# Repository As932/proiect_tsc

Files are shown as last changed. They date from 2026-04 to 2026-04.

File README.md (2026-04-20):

# ⌚ Smartwatch Hardware Design - nRF52840

Acest repository conține documentația și fișierele de fabricație (Schematic, PCB Layout, BOM, Pick and Place, Gerbers) pentru un prototip de smartwatch ultra-low-power. Proiectul este construit în jurul ecosistemului Nordic Semiconductor și pune accent pe eficiența energetică extremă (standby de ordinul microamperilor) și pe o topologie PCB densă.

---

## 🛠️ 1. Arhitectura Hardware & Componente

Sistemul este împărțit în patru blocuri logice majore, conform schemei electrice:

### 1.1 Procesare & Conectivitate Radio
* **Microcontroller (MCU):** Nordic **nRF52840** (ARM® Cortex®-M4F la 64 MHz). Ales pentru consumul excelent în Deep Sleep și suportul nativ Bluetooth 5.0 Low Energy (BLE).
* **Cristal RTC:** 32.768 KHz (cu condensatoare de sarcină de 12pF) pentru menținerea timpului real cu un consum minim de energie.
* **Antenă:** Antenă ceramică SMD tip Chip, model **2450AT18B100E** (Johanson Technology), acompaniată de o rețea pasivă (Pi-matching network) pentru adaptarea impedanței la 2.4 GHz.

### 1.2 Interfață Utilizator (Afișaj)
* **Ecran E-Paper (e-Ink):** Conectat la PCB printr-un conector FPC cu 24 de pini (**503480-2400**).
* **Circuit de Boost E-Paper:** Panourile e-Ink necesită tensiuni specifice pentru acționarea stratului de cerneală. Placa include circuitul complet de comandă recomandat, folosind un inductor de **68uH** (L5) și diode Schottky **MBR0530** (D1, D2, D3), alături de condensatorii de filtraj asociați (10uF, 47uF).

### 1.3 Senzor de Mișcare
* **IMU (Inertial Measurement Unit):** Bosch **BMA423**. Este un accelerometru digital pe 3 axe optimizat special pentru *wearables*. Conține algoritmi hardware integrați (low-power) pentru numărarea pașilor (pedometru) și detectarea gesturilor (ex: *tilt-to-wake*), scutind MCU-ul de calcule complexe.

### 1.4 Power Management (Alimentare)
* **LiPo Charger:** **BQ25180YBGR**. Un IC dedicat managementului bateriilor mici de tip litiu-polimer. Oferă un control precis al curentului de încărcare (esențial pentru bateriile de smartwatch) și terminare sigură a ciclului de încărcare.
* **Regulator DC/DC Buck-Boost:** **RT6150AWSC**. Aceasta este o componentă critică a designului. Deoarece bateria LiPo variază de la 4.2V (plină) la 3.0V (goală), acest convertor menține tensiunea sistemului (VOUT) la un nivel stabil de 3.3V, trecând automat din modul *Buck* (coborâtor) în modul *Boost* (ridicător) pe măsură ce bateria se descarcă.

---

## 📌 2. Alocarea Pinilor nRF52840 (Interfețe)

Conexiunile fizice între MCU și periferice au fost rutate pentru a minimiza încrucișările și a asigura integritatea semnalelor.

| Componentă | Pin MCU | Interfață / Rol | Justificare & Funcționalitate |
| :--- | :---: | :---: | :--- |
| **BMA423 (IMU)** | `[P0.06]` | I2C (SDA) | Magistrală de comunicație date. |
| **BMA423 (IMU)** | `[P0.07]` | I2C (SCL) | Magistrală de clock (SCL). BMA423 lucrează ca slave I2C. |
| **BMA423 (IMU)** | `[P0.08, P1.08]` | INT | Pin de interrupt hardware. Trezește MCU-ul când detectează o mișcare a încheieturii. |
| **E-Paper (EPD)** | `[P0.03]` | SPI (MOSI) | Magistrala SPI rapidă pentru trimiterea frame-buffer-ului (imaginii) către ecran. |
| **E-Paper (EPD)** | `[P0.02]` | SPI (SCK) | Clock pentru magistrala SPI. |
| **E-Paper (EPD)** | `[P0.17]` | GPIO (BUSY) | Pin de stare (Input). MCU-ul intră în sleep și așteaptă ca acest pin să semnalizeze terminarea refresh-ului fizic al ecranului. |
| **SWD / Debug** | N/A | SWDIO / SWDCLK | Programarea se face via un conector de suprafață **TC2030-IDC** (Tag-Connect) cu 6 pad-uri, economisind masiv spațiu pe placă. |

---

## 🔋 3. Analiza Consumului de Energie (Power Budget Estimativ)

Ecosistemul hardware a fost ales pentru a maximiza autonomia unei baterii de capacitate redusă (ex: 150-200 mAh).

1.  **Standby / Deep Sleep (Regim majoritar):** * nRF52840 (RTC activ) + BMA423 (Low-power mode) + RT6150 (Quiescent) = **Aprox. 5 - 10 µA**.
    * *E-Paper-ul consumă 0 µA pentru a menține imaginea afișată.*
2.  **Evenimente Active (Scurte):**
    * **Refresh Ecran:** Curentul absorbit de circuitul de boost este de **aprox. 8 - 15 mA** timp de ~1-2 secunde, doar în momentul actualizării.
    * **Transmisie BLE:** Vârfuri scurte de curent (Tx Peak) la transmiterea pachetelor radio.
3.  **Concluzie:** Curentul mediu de descărcare este dominat de cât de des se actualizează ecranul (ex: la minut vs. la secundă) și de cât de des se sincronizează Bluetooth-ul. Într-un regim optimizat de ceas de mână, hardware-ul permite funcționarea de ordinul săptămânilor.

---

## 📐 4. Design Log & Integrare Mecanică

### Layout PCB & Integritate Electromagnetică
* **Planuri de Masă & Via Stitching:** Pentru a ecrana zgomotul (EMI) și a asigura un nivel de referință stabil pentru circuitul RF (Antenă), placa dispune de planuri de masă (`GND`) solide pe ambele straturi (TOP și BOTTOM). Acestea sunt cusute între ele (Via Stitching) pe toată suprafața disponibilă.
* **Zona RF:** S-a creat un *Polygon Cutout* (zonă liberă de cupru) strict sub și în jurul antenei ceramice 2450AT18B100E pentru a nu ecrana și a nu dezacorda propagarea undelor de 2.4 GHz.
* **Necking Down pe Alimentare:** Traseele de putere au fost rutate pe cât posibil cu o lățime de 0.3mm. Totuși, în zonele foarte congestionate (în proximitatea PMIC-ului BQ25180 și a procesorului), traseele au fost îngustate local (*neck-down*) pentru a permite amplasarea condensatorilor de decuplare (ex: C38, C39) cât mai aproape de pini.

### Status Integrare 3D & Carcasă (Mechanical)
1. **Modelul Nativ:** Fișierul `.f3z` din folderul *Mechanical* conține designul nativ din Fusion 360 al plăcii. Au fost rezolvate erorile vizuale de extrudare a pachetelor lipsă (cărămizile negre) specifice componentelelor custom.
2. **Exploded View (WIP):** Etapa de asamblare este în desfășurare. S-a realizat exportul plăcii (Switch to 3D PCB). Amplasarea conceptuală a dispozitivului urmează un design tip "sandwich":
   * **Bateria:** Plasată sub PCB (pe fața BOTTOM).
   * **Ecranul E-Paper:** Poziționat deasupra PCB-ului (pe fața TOP), conectat prin cablul FPC îndoit.
   * *Notă:* Modelele 3D exacte pentru baterie și display urmează să fie importate și aliniate pentru exportul final de ansamblu tip `.step`.

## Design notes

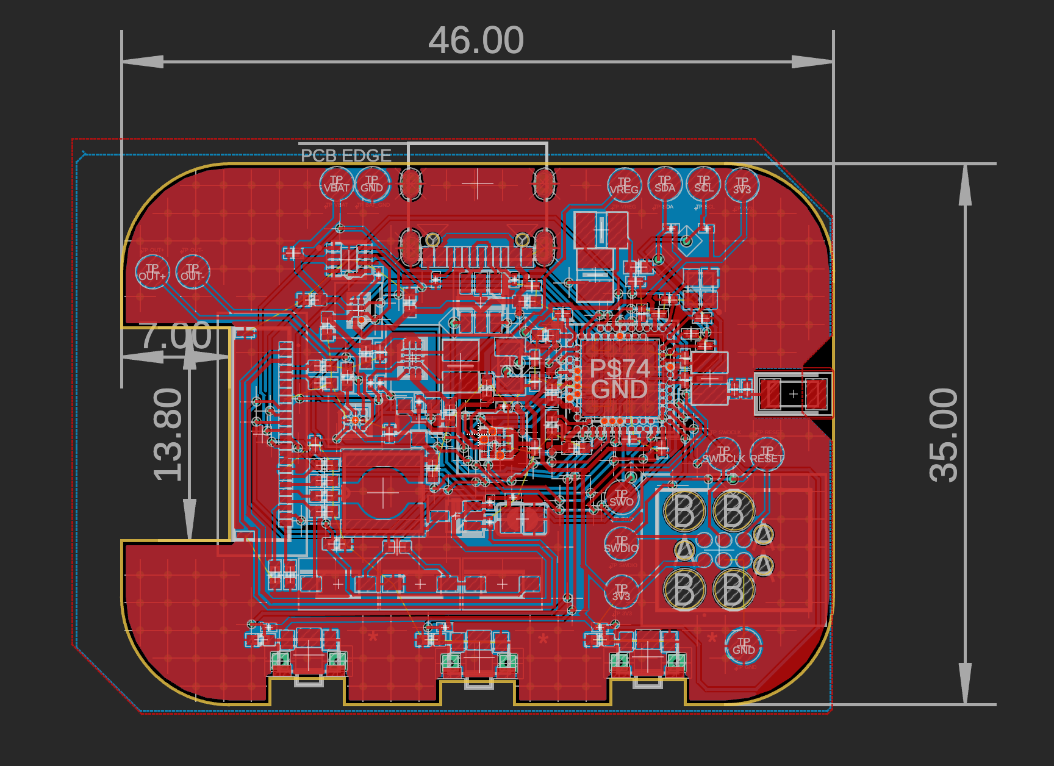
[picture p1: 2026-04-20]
Images/Screenshot 2026-04-20 at 15.04.27.png

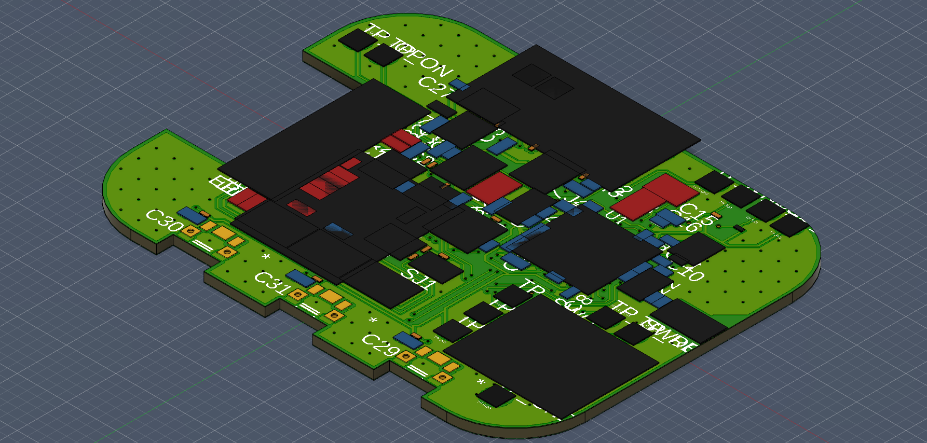
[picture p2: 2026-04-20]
Images/Screenshot 2026-04-20 at 15.04.39.png

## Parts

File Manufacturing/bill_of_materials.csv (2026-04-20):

Reference Designators | Quantity | Description | Package | Value | Manufacturer | Manufacturer Part Number | Vendor | Vendor Part Number | Top/Bottom
 | 1 | Board | Board
ANT1 | 1 | Antennas 2.45GHz ANTENNA | 2450AT18B100E_ANTC3216X140N | 2450AT18B100E |  |  |  |  | Top
C1-EP-DR, C24, C39 | 3 | Generic chip capacitor | NORDIC_NRF_3_RESC0402_N | 10uF |  |  |  |  | Top
C1, C2, C17, C18 | 4 | Generic chip capacitor | NORDIC_NRF_3_RESC0201_N | 12pF |  |  |  |  | Top
C2-EP-DR, C6, C14, C20, C21, C43 | 6 | Generic chip capacitor | NORDIC_NRF_3_RESC0402_N | 4.7uF |  |  |  |  | Top
C3, C4 | 2 | Generic chip capacitor | NORDIC_NRF_3_RESC0201_N | 1pF |  |  |  |  | Top
C5, C7, C8, C12, C19 | 5 | Generic chip capacitor | NORDIC_NRF_3_RESC0201_N | 100nF |  |  |  |  | Top
C9 | 1 | Generic chip capacitor | NORDIC_NRF_3_RESC0201_N | 820pF N.C. |  |  |  |  | Top
C10, C13, C22 | 3 | Generic chip capacitor | NORDIC_NRF_3_RESC0201_N | N.C. |  |  |  |  | Top
C11 | 1 | Generic chip capacitor | NORDIC_NRF_3_RESC0201_N | 100pF |  |  |  |  | Top
C15 | 1 | Generic chip capacitor | NORDIC_NRF_3_RESC0402_N | 1.0uF |  |  |  |  | Top
C16 | 1 | Generic chip capacitor | NORDIC_NRF_3_RESC0201_N | 47nF |  |  |  |  | Top
C23, C27, C34, C42, EPD_C5 | 5 | Generic chip capacitor | NORDIC_NRF_3_RESC0201_N | 0.1uF |  |  |  |  | Top
C25, C33 | 2 | Generic chip capacitor | NORDIC_NRF_3_RESC0402_N | 22uF |  |  |  |  | Top
C29, C30, C31, C32, C37, C38, EPD_C1, EPD_C2, EPD_C6, EPD_C7, EPD_C8, EPD_C9, EPD_C10, EPD_C11, EPD_C12 | 15 | Generic chip capacitor | NORDIC_NRF_3_RESC0402_N | 1uF |  |  |  |  | Top
D2, D4, D5 | 3 | ON SEMICONDUCTOR - MBR0530 - DIODE, SCHOTTKY, 0.5A, 30V, SOD-123 | SOD3716X135N | MBR0530 |  |  |  |  | Top
D3 | 1 | Low Cap. ESD Protection Auto SOT-23-6 STMicroelectronics USBLC6-2SC6Y, Dual Uni-Directional TVS Diode Array, 6-Pin SOT-23 | SOT95P280X145-6N | USBLC6-2SC6Y |  |  |  |  | Top
IC1 | 1 | Charger IC Lithium Ion/Polymer, Lithium Iron Phosphate 8-DSBGA (1.6x1.1) | BQ25180YBGR_BGA8C40P2X4_100X155X50 | BQ25180YBGR |  |  |  |  | Top
IC2 | 1 | Haptic Driver for ERM/LRA with Built-In Library and Smart Loop Architecture | DRV2605YZFR_BGA9C50P3X3_144X144X62 | DRV2605YZFR |  |  |  |  | Top
IC3 | 1 | Accelerometers Triaxial low-g 12bit Acceleration Sensor | BMA423_BMA423 | BMA423 |  |  |  |  | Top
IC9 | 1 | Buck-Boost Regulator Positive Output Step-Up/Step-Down I2C DC-DC Controller IC 15-WL-CSP (BSC) (1.4x2.3) | RT6160AWSC_BGA15C40P3X5_140X230X60 | RT6160AWSC |  |  |  |  | Top
J1 | 1 | FFC & FPC Connectors 0.5mm FPC RA SMT Dual Contact 24Ckt | 503480-2400_5034802400 | 503480-2400 |  |  |  |  | Top
J2 | 1 | CABLE ADAPTER 6 POS | TC2030-IDC_TC2030IDC | TC2030-IDC |  |  |  |  | Top
J4 | 1 | Check availability | KINGHELM_KH-TYPE-C-16P | KH-TYPE-C-16P |  |  |  |  | Top
L1 | 1 | SMD / SMT Inductors (Coils), L=0.47?H, L x W x T : | MLP2016SR47MT0S1_INDC2016X100N | 3.9nH |  |  |  |  | Top
L2 | 1 | SMD / SMT Inductors (Coils), L=0.47?H, L x W x T : | MLP2016SR47MT0S1_INDC2016X100N | 10uH |  |  |  |  | Top
L3 | 1 | SMD / SMT Inductors (Coils), L=0.47?H, L x W x T : | MLP2016SR47MT0S1_INDC2016X100N | 15nH |  |  |  |  | Top
L5 | 1 |  | ESP32_C6_LIBRARY_2_IND_4828-WE-TPC_WRE | 68uH |  |  |  |  | Top
L7 | 1 | SMD / SMT Inductors (Coils), L=0.47?H, L x W x T : | MLP2016SR47MT0S1_INDC2016X100N | FTC252012SR47MBCA |  |  |  |  | Top
Q1 | 1 | P-channel MOSFETs | ESP32_WROVER_SPARKFUN-DISCRETESEMI_SOT23-3 | 20V/4.2A/52mΩ/1.4W |  |  |  |  | Top
Q3 | 1 | MOSFET N-Ch 30V 1.5A TrenchFET SC70 Vishay Si1308EDL-T1-GE3 N-channel MOSFET Transistor, 1.5 A, 30 V, 3-Pin SC-70 | SOT65P210X110-3N | SI1308EDL-T1-GE3 |  |  |  |  | Top
R_PWR_EPD, R2_EP_DR, R5, R7, R8, R9 | 6 | 7.68k 0201 Thin Film Surface Mount Fixed Resistor +/-0.5% 0.031W CPF0201D7K68C1 | CPF0201D7K68C1_0201 | 10K |  |  |  |  | Top
R_TYPE_SEL | 1 | 7.68k 0201 Thin Film Surface Mount Fixed Resistor +/-0.5% 0.031W CPF0201D7K68C1 | CPF0201D7K68C1_0201 | 2.2 |  |  |  |  | Top
R1_EP_DR | 1 | 7.68k 0201 Thin Film Surface Mount Fixed Resistor +/-0.5% 0.031W CPF0201D7K68C1 | CPF0201D7K68C1_0201 | 0.47 |  |  |  |  | Top
R1_USB, R2_USB | 2 | 7.68k 0201 Thin Film Surface Mount Fixed Resistor +/-0.5% 0.031W CPF0201D7K68C1 | CPF0201D7K68C1_0201 | 5K1 |  |  |  |  | Top
R2, R3, R4 | 3 | 7.68k 0201 Thin Film Surface Mount Fixed Resistor +/-0.5% 0.031W CPF0201D7K68C1 | CPF0201D7K68C1_0201 | 0 |  |  |  |  | Top
R17, R18 | 2 | 7.68k 0201 Thin Film Surface Mount Fixed Resistor +/-0.5% 0.031W CPF0201D7K68C1 | CPF0201D7K68C1_0201 | 3K3 |  |  |  |  | Top
SJ1 | 1 | SMD solder JUMPER | JUMPER_SJ |  |  |  |  |  | Top
SW2, SW3, SW4 | 3 |  | SW_EVP-AKE31A_PAN | 0 |  |  |  |  | Top
TP_3.3V, TP_3V3, TP_BAT_GND, TP_GND, TP_ON, TP_OP, TP_RESET, TP_SCL, TP_SDA, TP_SWDCLK, TP_SWDIO, TP_SWO, TP_VBAT, TP_VREG | 14 | Test pad | HECTOR_WATCH_1_TP20R | HECTOR_WATCH_1_TPTP20R |  |  |  |  | Top
U1 | 1 | nRF52840 | NORDIC_NRF_4_AQFN50P700X700X85_HS-74N | NRF52840_QF |  |  |  |  | Top
U3 | 1 | Check availability | SON50P200X200X80-9N | MAX17048G+T10 |  |  |  |  | Top
X1 | 1 |  | NORDIC_NRF_BT-XTAL_2016_N | 32MHz |  |  |  |  | Top
X2 | 1 |  | NORDIC_NRF_1_XTAL_3215_N | 32.768kHz |  |  |  |  | Top

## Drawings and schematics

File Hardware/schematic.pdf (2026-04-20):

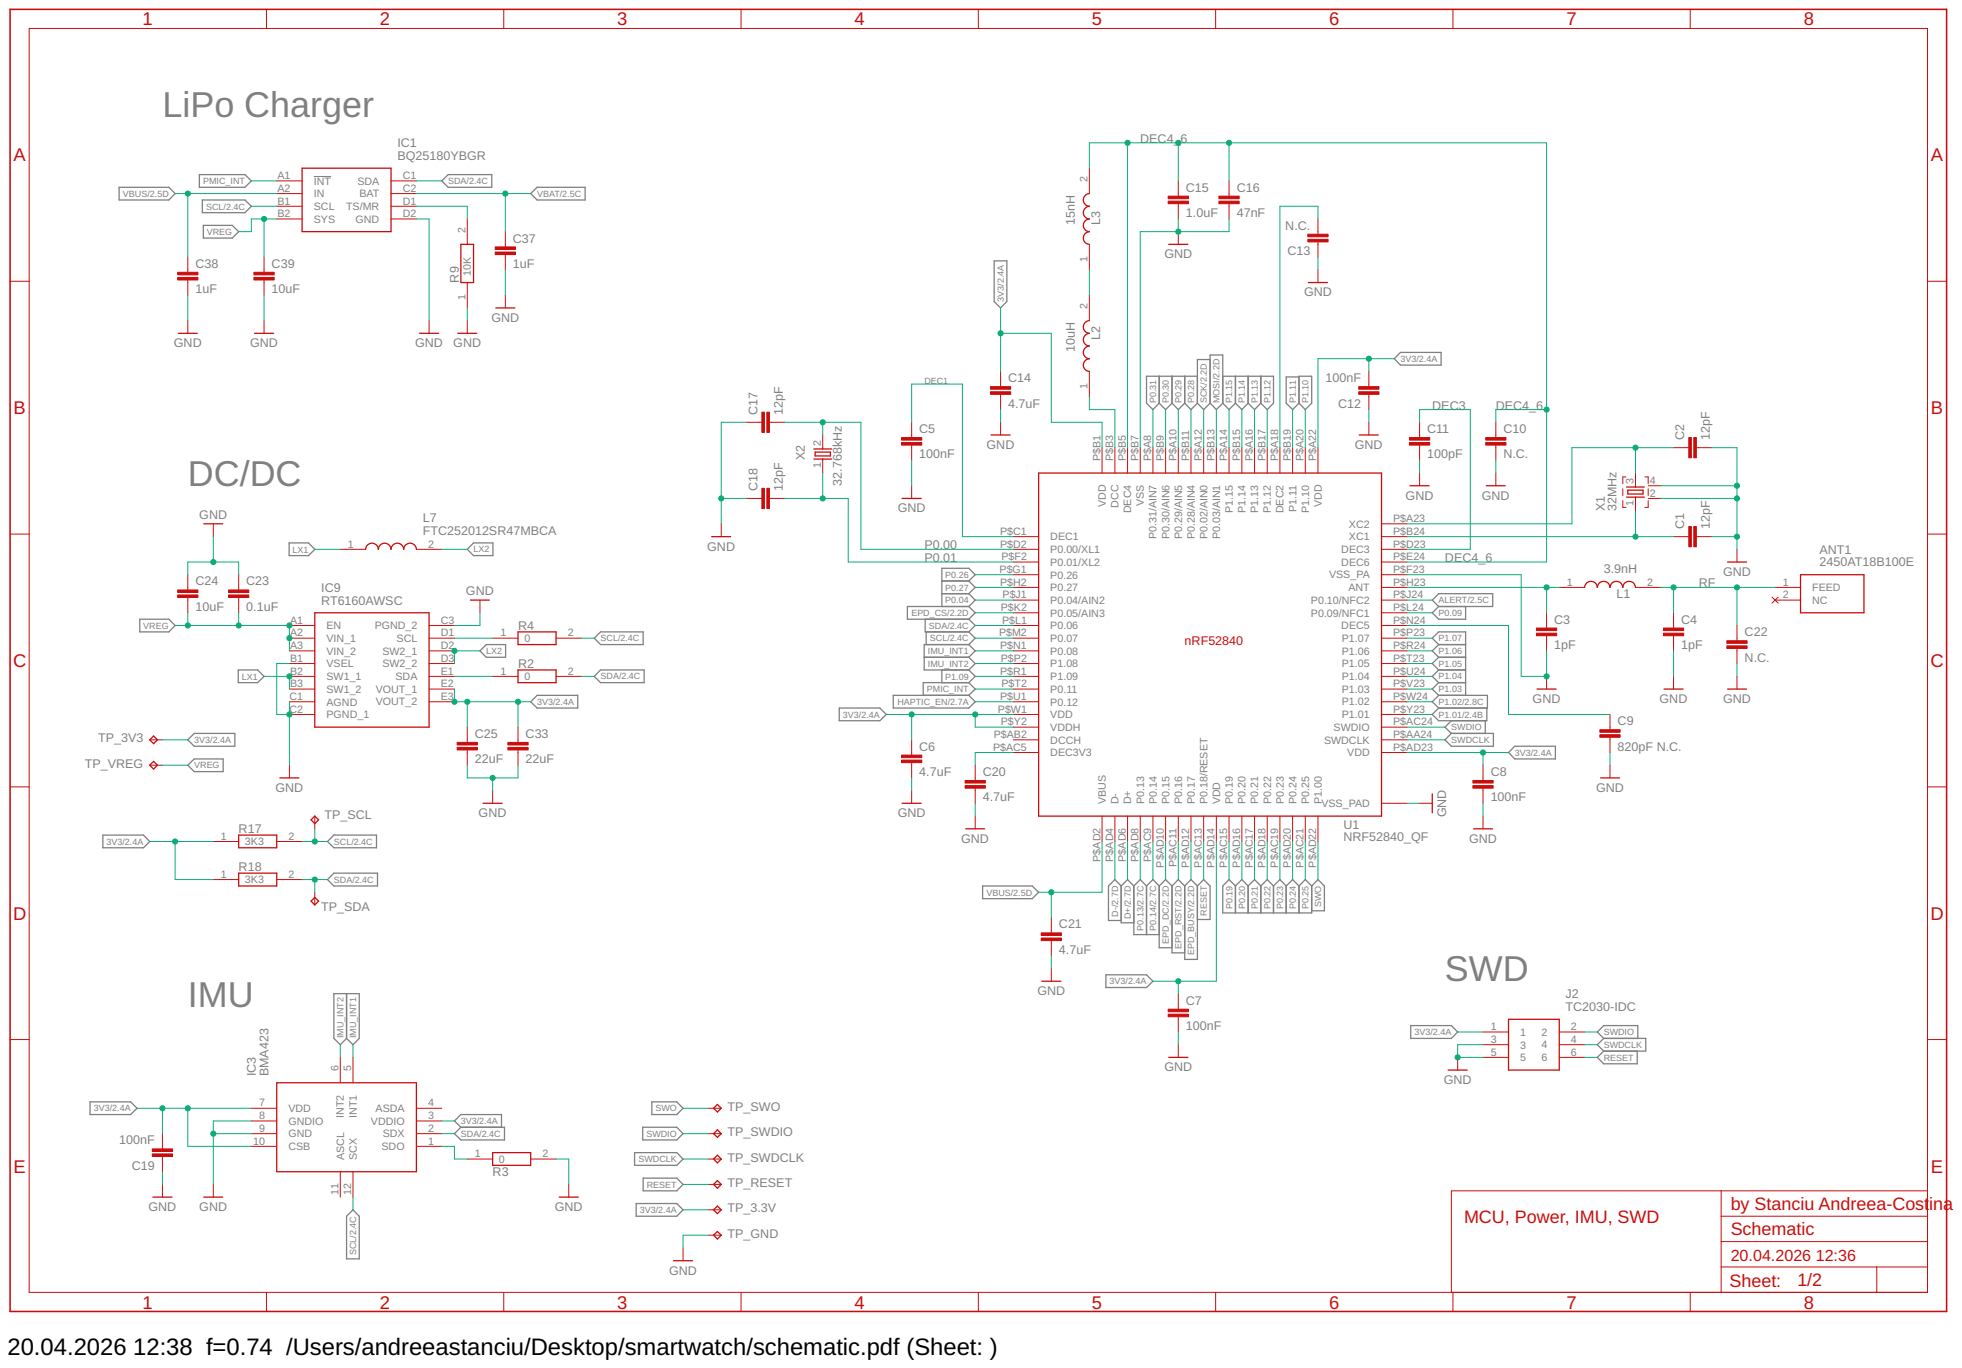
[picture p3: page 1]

MHz GND GND GND

by Stanciu Andreea-Costina Sheet:
Schematic

MCU, Power, IMU, SWD

20.04.2026 12:38 f=0.74 /Users/andreeastanciu/Desktop/smartwatch/schematic.pdf (Sheet: )

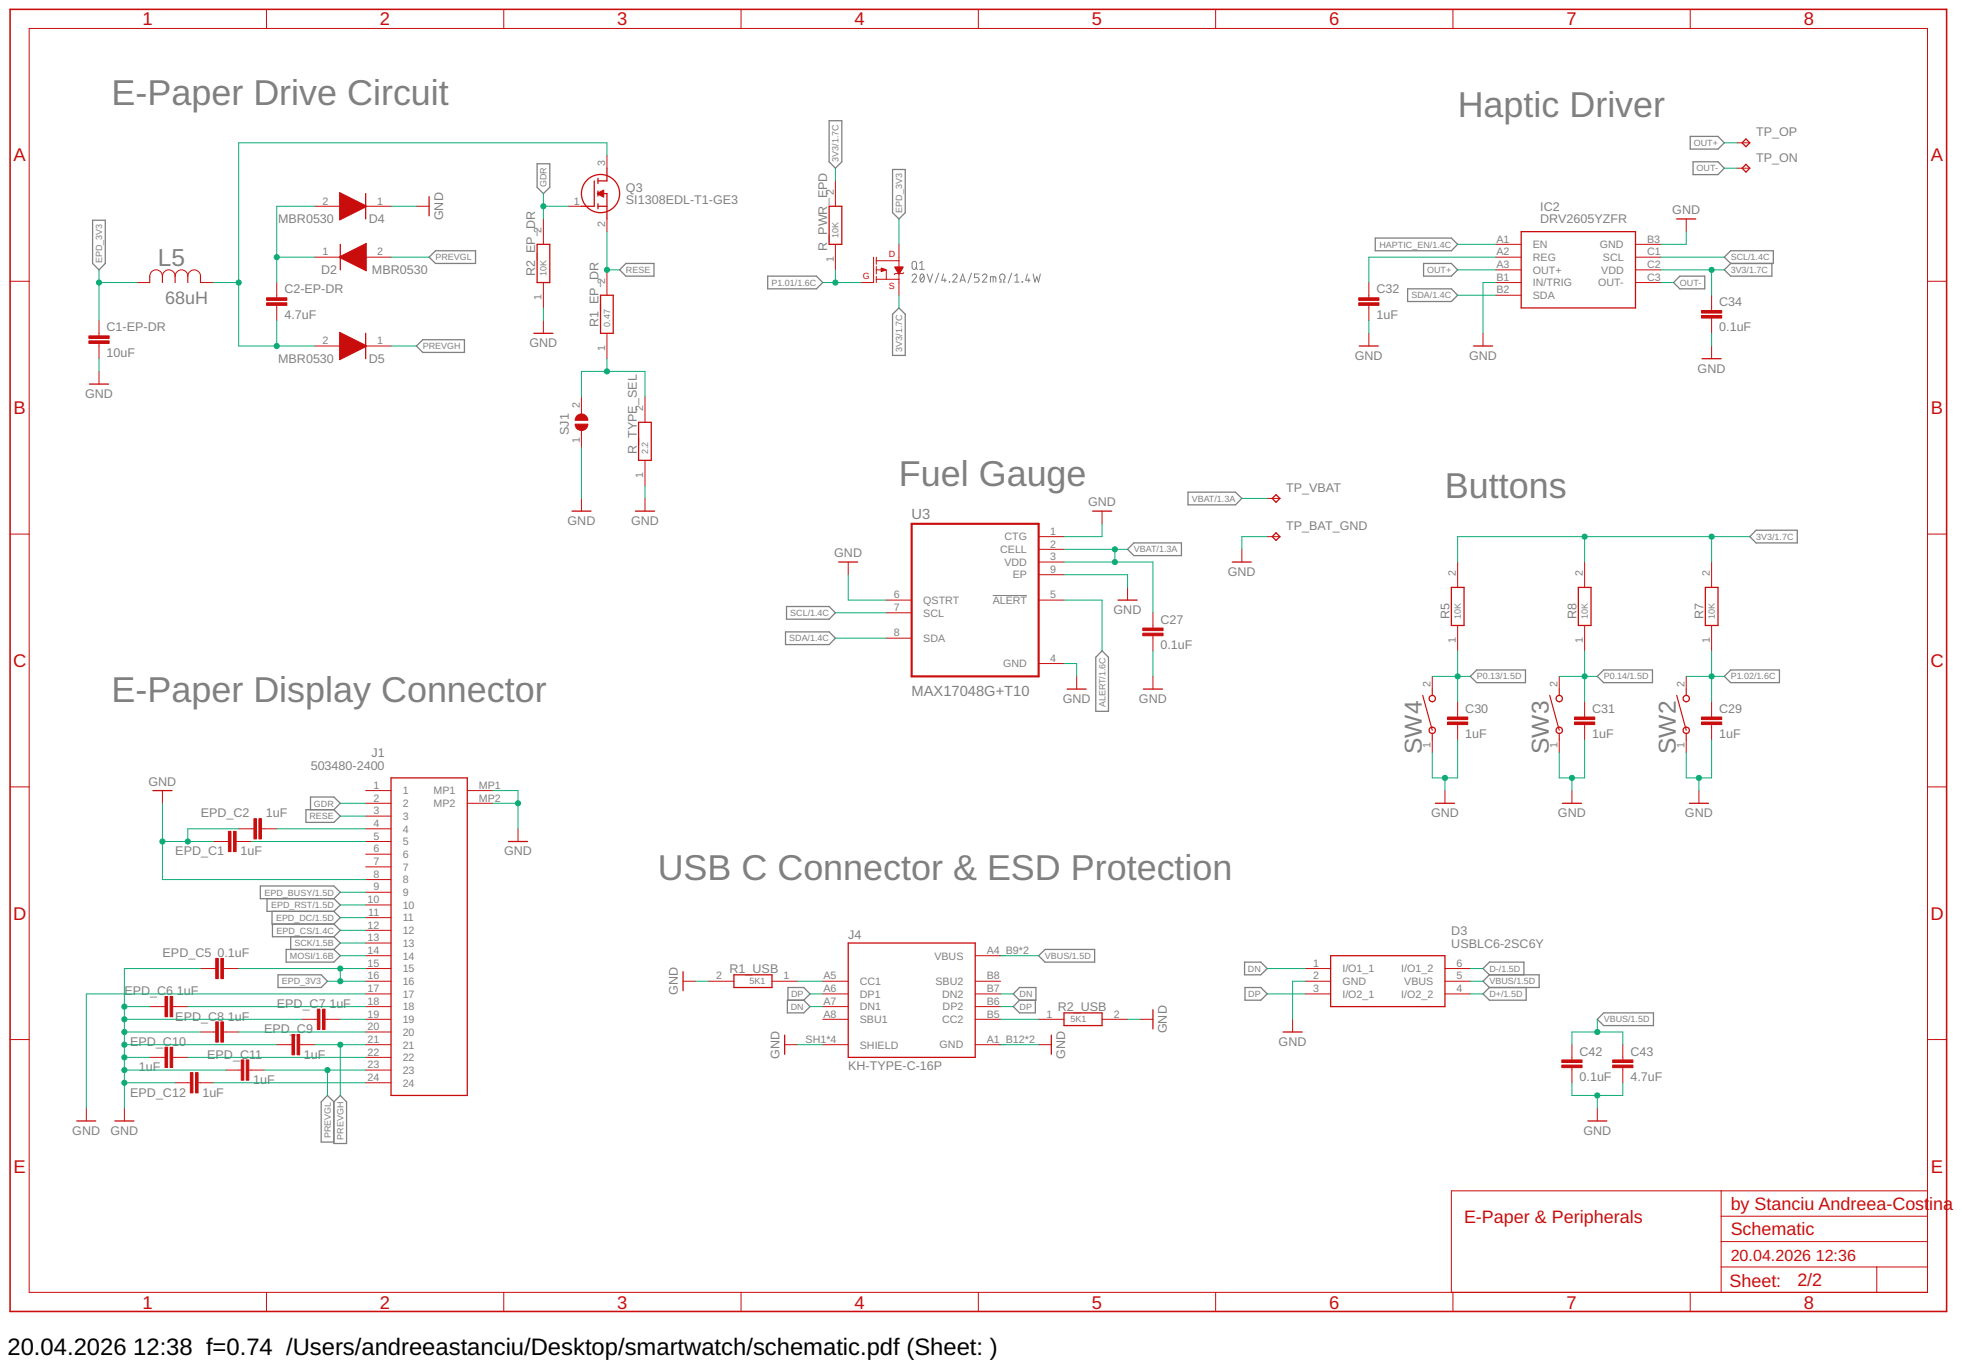
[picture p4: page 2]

USB C Connector & ESD Protection

20.04.2026 12:38 f=0.74 /Users/andreeastanciu/Desktop/smartwatch/schematic.pdf (Sheet: )

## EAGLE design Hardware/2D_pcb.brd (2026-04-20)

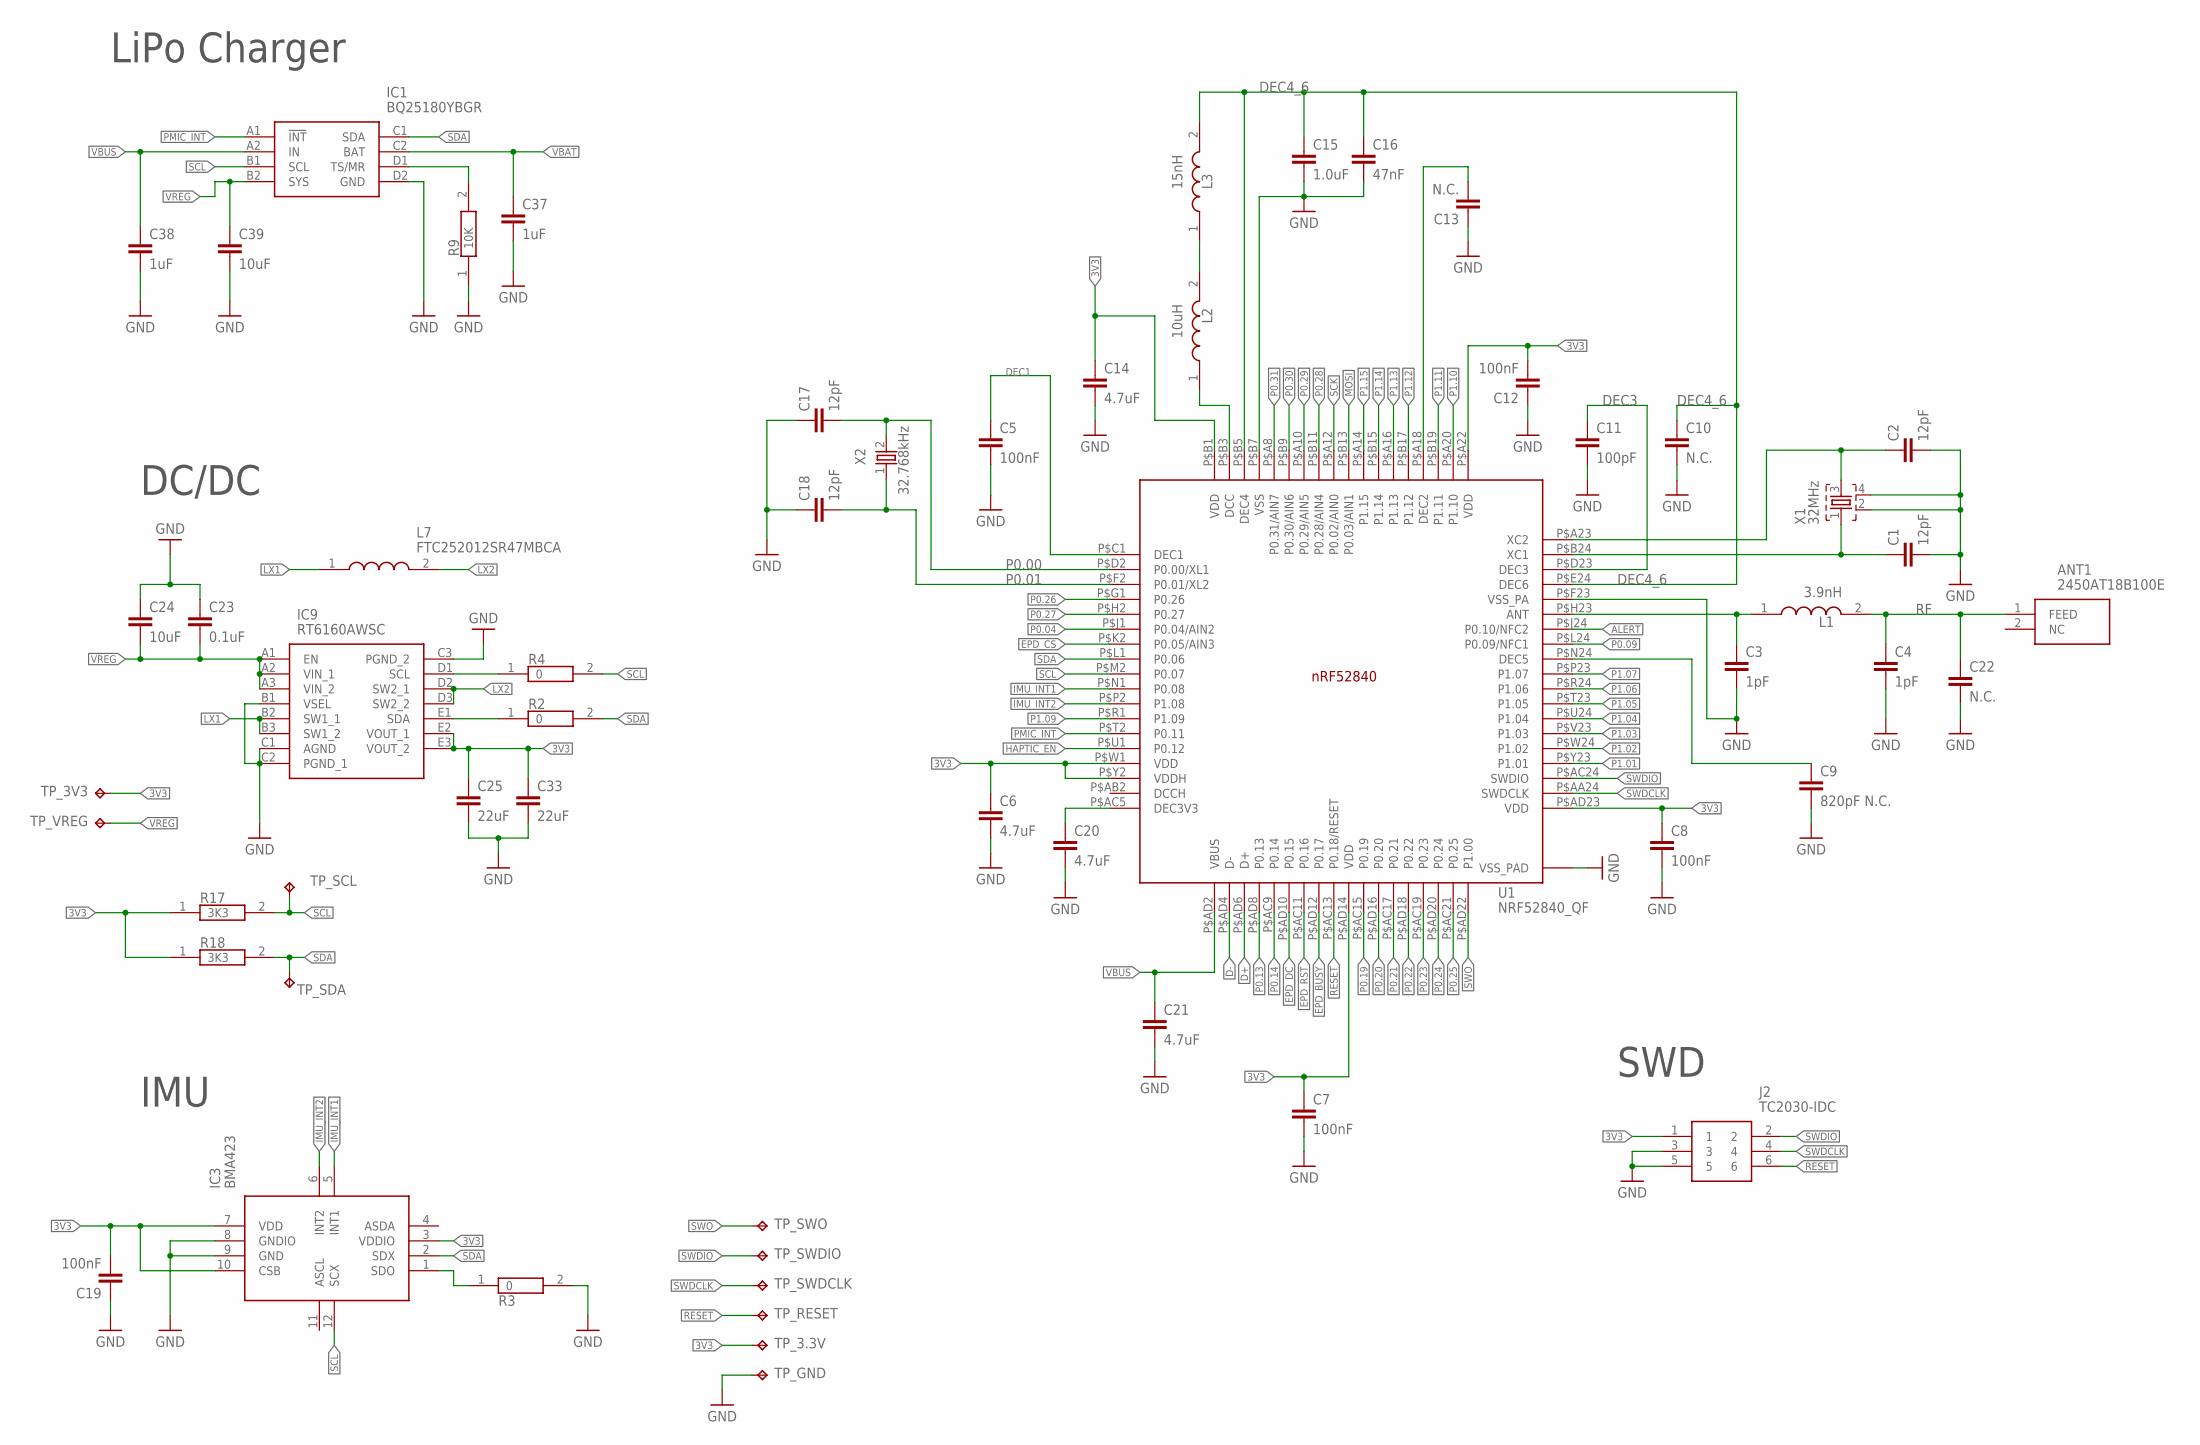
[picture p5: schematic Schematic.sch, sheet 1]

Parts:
ANT1: 2450AT18B100E; 2450AT18B100E_ANTC3216X140N
C1, C2, C17, C18: 12pF; NORDIC_NRF_3_RESC0201_N
C3, C4: 1pF; NORDIC_NRF_3_RESC0201_N
C5, C7, C8, C12, C19: 100nF; NORDIC_NRF_3_RESC0201_N
C6, C14, C20, C21: 4.7uF; NORDIC_NRF_3_RESC0402_N
C9: 820pF N.C.; NORDIC_NRF_3_RESC0201_N
C10, C13, C22: N.C.; NORDIC_NRF_3_RESC0201_N
C11: 100pF; NORDIC_NRF_3_RESC0201_N
C15: 1.0uF; NORDIC_NRF_3_RESC0402_N
C16: 47nF; NORDIC_NRF_3_RESC0201_N
C23: 0.1uF; NORDIC_NRF_3_RESC0201_N
C24, C39: 10uF; NORDIC_NRF_3_RESC0402_N
C25, C33: 22uF; NORDIC_NRF_3_RESC0402_N
C37, C38: 1uF; NORDIC_NRF_3_RESC0402_N
IC1: BQ25180YBGR; BQ25180YBGR_BGA8C40P2X4_100X155X50
IC3: BMA423; BMA423_BMA423
IC9: RT6160AWSC; RT6160AWSC_BGA15C40P3X5_140X230X60
J2: TC2030-IDC; TC2030-IDC_TC2030IDC
L1: 3.9nH; MLP2016SR47MT0S1_INDC2016X100N
L2: 10uH; MLP2016SR47MT0S1_INDC2016X100N
L3: 15nH; MLP2016SR47MT0S1_INDC2016X100N
L7: FTC252012SR47MBCA; MLP2016SR47MT0S1_INDC2016X100N
R2, R3, R4: 0; CPF0201D7K68C1_0201
R9: 10K; CPF0201D7K68C1_0201
R17, R18: 3K3; CPF0201D7K68C1_0201
TP_3.3V, TP_3V3: HECTOR_WATCH_1_TPTP20R; HECTOR_WATCH_1_TP20R
TP_GND: HECTOR_WATCH_1_TPTP20R; HECTOR_WATCH_1_TP20R
TP_RESET: HECTOR_WATCH_1_TPTP20R; HECTOR_WATCH_1_TP20R
TP_SCL: HECTOR_WATCH_1_TPTP20R; HECTOR_WATCH_1_TP20R
TP_SDA: HECTOR_WATCH_1_TPTP20R; HECTOR_WATCH_1_TP20R
TP_SWDCLK: HECTOR_WATCH_1_TPTP20R; HECTOR_WATCH_1_TP20R
TP_SWDIO: HECTOR_WATCH_1_TPTP20R; HECTOR_WATCH_1_TP20R
TP_SWO: HECTOR_WATCH_1_TPTP20R; HECTOR_WATCH_1_TP20R
TP_VREG: HECTOR_WATCH_1_TPTP20R; HECTOR_WATCH_1_TP20R
U1: NRF52840_QF; NORDIC_NRF_4_AQFN50P700X700X85_HS-74N
X1: 32MHz; NORDIC_NRF_BT-XTAL_2016_N
X2: 32.768kHz; NORDIC_NRF_1_XTAL_3215_N

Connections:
3V3: C6.1, C7.1, C8.1, C12.2, C14.1, C19.2, C25.1, C33.1, IC3.3 (VDDIO), IC3.7 (VDD), IC3.10 (CSB), IC9.E2 (VOUT_1), IC9.E3 (VOUT_2), J2.1, R17.1, R18.1, TP_3.3V.TP, TP_3V3.TP, U1.P$A22 (VDD), U1.P$AD14 (VDD), U1.P$AD23 (VDD), U1.P$B1 (VDD), U1.P$W1 (VDD), U1.P$Y2 (VDDH); also elsewhere on the board
ALERT: U1.P$J24 (P0.10/NFC2); also elsewhere on the board
D+: U1.P$AD6 (D+); also elsewhere on the board
D-: U1.P$AD4 (D-); also elsewhere on the board
DEC1: C5.1, U1.P$C1 (DEC1)
DEC3: C11.1, U1.P$D23 (DEC3)
DEC4_6: C10.1, C15.1, C16.1, L3.2, U1.P$B5 (DEC4), U1.P$E24 (DEC6)
EPD_BUSY: U1.P$AD12 (P0.17); also elsewhere on the board
EPD_CS: U1.P$K2 (P0.05/AIN3); also elsewhere on the board
EPD_DC: U1.P$AD10 (P0.15); also elsewhere on the board
EPD_RST: U1.P$AC11 (P0.16); also elsewhere on the board
GND: C1.2, C2.2, C3.2, C4.2, C5.2, C6.2, C7.2, C8.2, C9.2, C10.2, C11.2, C12.1, C13.1, C14.2, C15.2, C16.2, C17.1, C18.1, C19.1, C20.2, C21.2, C22.2, C23.1, C24.1, C25.2, C33.2, C37.2, C38.2, C39.2, IC1.D2 (GND), IC3.8 (GNDIO), IC3.9 (GND), IC9.B1 (VSEL), IC9.C1 (AGND), IC9.C2 (PGND_1), IC9.C3 (PGND_2), J2.3, J2.5, R3.2, R9.1, TP_GND.TP, U1.P$74 (VSS_PAD), U1.P$75 (VSS_PAD), U1.P$76 (VSS_PAD), U1.P$77 (VSS_PAD), U1.P$78 (VSS_PAD), U1.P$79 (VSS_PAD), U1.P$80 (VSS_PAD), U1.P$81 (VSS_PAD), U1.P$82 (VSS_PAD), U1.P$83 (VSS_PAD), U1.P$84 (VSS_PAD), U1.P$85 (VSS_PAD), U1.P$86 (VSS_PAD), U1.P$87 (VSS_PAD), U1.P$88 (VSS_PAD), U1.P$89 (VSS_PAD), U1.P$90 (VSS_PAD), U1.P$B7 (VSS), U1.P$F23 (VSS_PA), X1.2, X1.4; also elsewhere on the board
HAPTIC_EN: U1.P$U1 (P0.12); also elsewhere on the board
IMU_INT1: IC3.5 (INT1), U1.P$N1 (P0.08)
IMU_INT2: IC3.6 (INT2), U1.P$P2 (P1.08)
LX1: IC9.B2 (SW1_1), IC9.B3 (SW1_2), L7.1
LX2: IC9.D2 (SW2_1), IC9.D3 (SW2_2), L7.2
MOSI: U1.P$B13 (P0.03/AIN1); also elsewhere on the board
unnamed: IC1.D1 (TS/MR), R9.2
unnamed: IC9.D1 (SCL), R4.1
unnamed: IC9.E1 (SDA), R2.1
unnamed: IC3.1 (SDO), R3.1
unnamed: C20.1, U1.P$AC5 (DEC3V3)
unnamed: L2.1, U1.P$B3 (DCC)
unnamed: L2.2, L3.1
unnamed: C13.2, U1.P$A18 (DEC2)
unnamed: C2.1, U1.P$A23 (XC2), X1.3
unnamed: C1.1, U1.P$B24 (XC1), X1.1
unnamed: C3.1, L1.1, U1.P$H23 (ANT)
unnamed: C9.1, U1.P$N24 (DEC5)
P0.00: C17.2, U1.P$D2 (P0.00/XL1), X2.2
P0.01: C18.2, U1.P$F2 (P0.01/XL2), X2.1
P0.04: U1.P$J1 (P0.04/AIN2)
P0.09: U1.P$L24 (P0.09/NFC1)
P0.13: U1.P$AD8 (P0.13); also elsewhere on the board
P0.14: U1.P$AC9 (P0.14); also elsewhere on the board
P0.19: U1.P$AC15 (P0.19)
P0.20: U1.P$AD16 (P0.20)
P0.21: U1.P$AC17 (P0.21)
P0.22: U1.P$AD18 (P0.22)
P0.23: U1.P$AC19 (P0.23)
P0.24: U1.P$AD20 (P0.24)
P0.25: U1.P$AC21 (P0.25)
P0.26: U1.P$G1 (P0.26)
P0.27: U1.P$H2 (P0.27)
P0.28: U1.P$B11 (P0.28/AIN4)
P0.29: U1.P$A10 (P0.29/AIN5)
P0.30: U1.P$B9 (P0.30/AIN6)
P0.31: U1.P$A8 (P0.31/AIN7)
P1.01: U1.P$Y23 (P1.01); also elsewhere on the board
P1.02: U1.P$W24 (P1.02); also elsewhere on the board
P1.03: U1.P$V23 (P1.03)
P1.04: U1.P$U24 (P1.04)
P1.05: U1.P$T23 (P1.05)
P1.06: U1.P$R24 (P1.06)
P1.07: U1.P$P23 (P1.07)
P1.09: U1.P$R1 (P1.09)
P1.10: U1.P$A20 (P1.10)
P1.11: U1.P$B19 (P1.11)
P1.12: U1.P$B17 (P1.12)
P1.13: U1.P$A16 (P1.13)
P1.14: U1.P$B15 (P1.14)
P1.15: U1.P$A14 (P1.15)
PMIC_INT: IC1.A1 (!INT), U1.P$T2 (P0.11)
RESET: J2.6, TP_RESET.TP, U1.P$AC13 (P0.18/RESET)
RF: ANT1.1 (FEED), C4.1, C22.1, L1.2
SCK: U1.P$A12 (P0.02/AIN0); also elsewhere on the board
SCL: IC1.B1 (SCL), IC3.12 (SCX), R4.2, R17.2, TP_SCL.TP, U1.P$M2 (P0.07); also elsewhere on the board
SDA: IC1.C1 (SDA), IC3.2 (SDX), R2.2, R18.2, TP_SDA.TP, U1.P$L1 (P0.06); also elsewhere on the board
SWDCLK: J2.4, TP_SWDCLK.TP, U1.P$AA24 (SWDCLK)
SWDIO: J2.2, TP_SWDIO.TP, U1.P$AC24 (SWDIO)
SWO: TP_SWO.TP, U1.P$AD22 (P1.00)
VBAT: C37.1, IC1.C2 (BAT); also elsewhere on the board
VBUS: C21.1, C38.1, IC1.A2 (IN), U1.P$AD2 (VBUS); also elsewhere on the board
VREG: C23.2, C24.2, C39.1, IC1.B2 (SYS), IC9.A1 (EN), IC9.A2 (VIN_1), IC9.A3 (VIN_2), TP_VREG.TP

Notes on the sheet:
LiPo Charger
DC/DC
IMU
SWD

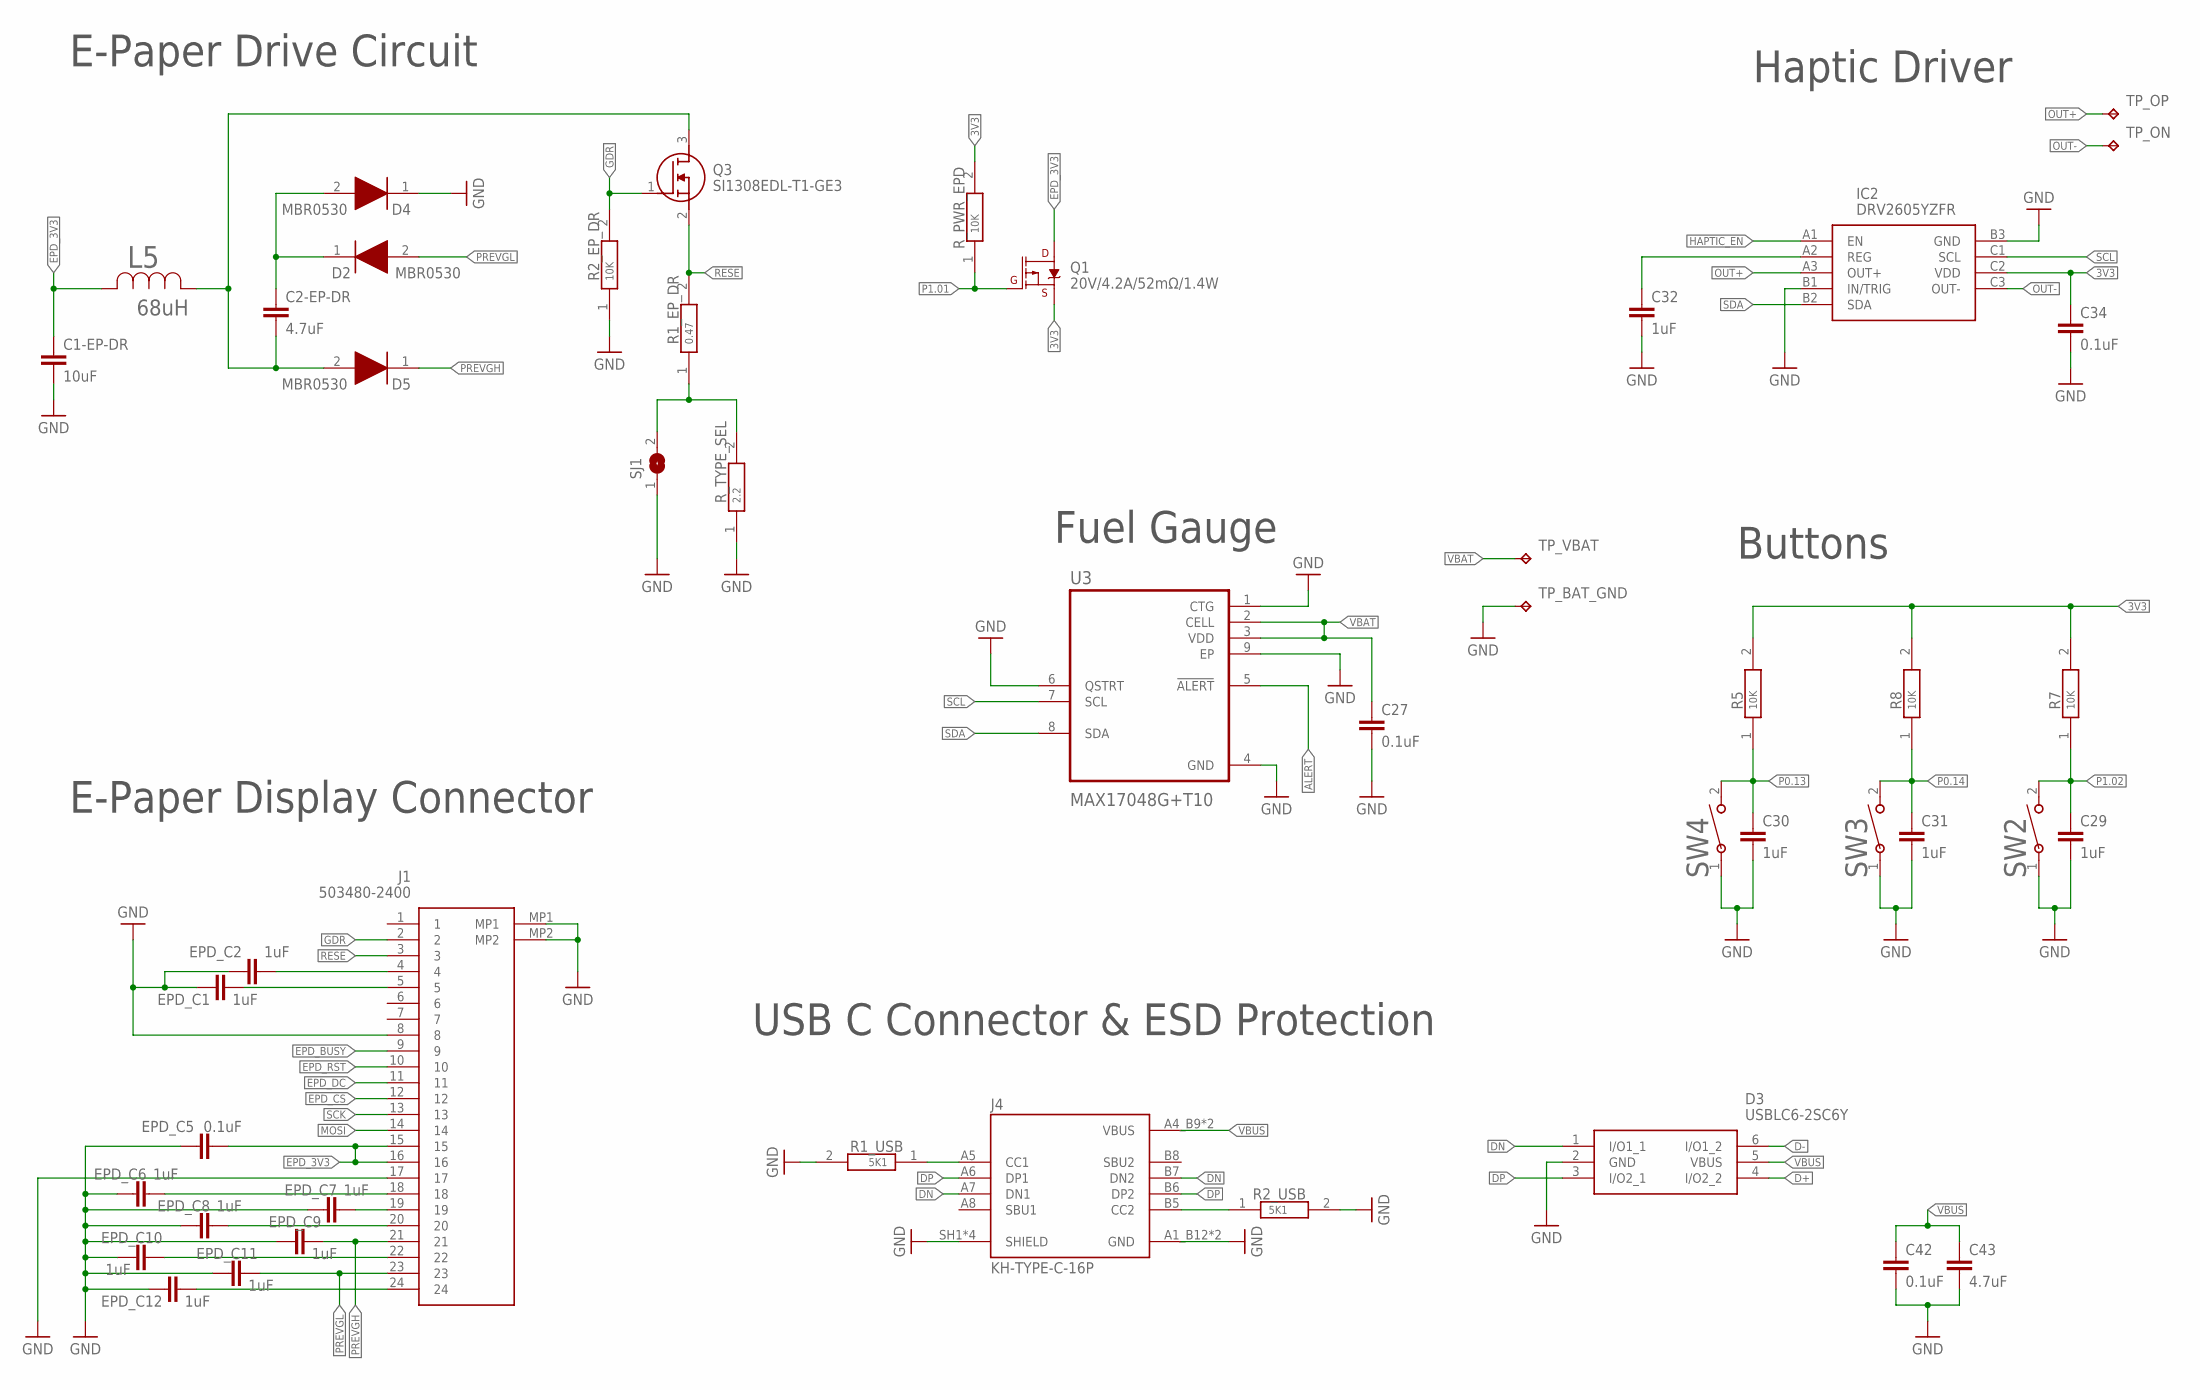
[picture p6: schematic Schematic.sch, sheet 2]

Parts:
C1-EP-DR: 10uF; NORDIC_NRF_3_RESC0402_N
C2-EP-DR, C43: 4.7uF; NORDIC_NRF_3_RESC0402_N
C27, C34, C42: 0.1uF; NORDIC_NRF_3_RESC0201_N
C29, C30, C31, C32: 1uF; NORDIC_NRF_3_RESC0402_N
D2, D4, D5: MBR0530; ESP32_C6_LIBRARY_5_SOD3716X135N
D3: USBLC6-2SC6Y; ESP32_C6_LIBRARY_3_SOT95P280X145-6N
EPD_C1, EPD_C2, EPD_C6, EPD_C7, EPD_C8, EPD_C9, EPD_C10, EPD_C11, EPD_C12: 1uF; NORDIC_NRF_3_RESC0402_N
EPD_C5: 0.1uF; NORDIC_NRF_3_RESC0201_N
IC2: DRV2605YZFR; DRV2605YZFR_BGA9C50P3X3_144X144X62
J1: 503480-2400; 503480-2400_5034802400
J4: KH-TYPE-C-16P; KH-TYPE-C-16P_KINGHELM_KH-TYPE-C-16P
L5: 68uH; ESP32_C6_LIBRARY_2_IND_4828-WE-TPC_WRE
Q1: 20V/4.2A/52mΩ/1.4W; ESP32_C6_LIBRARY_4_ESP32_C6_LIBRARY_4_ESP32_C6_LIBRARY_4_ES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
Q3: SI1308EDL-T1-GE3; ESP32_C6_LIBRARY_6_SOT65P210X110-3N
R1_EP_DR: 0.47; CPF0201D7K68C1_0201
R1_USB, R2_USB: 5K1; CPF0201D7K68C1_0201
R2_EP_DR, R5, R7, R8: 10K; CPF0201D7K68C1_0201
R_PWR_EPD: 10K; CPF0201D7K68C1_0201
R_TYPE_SEL: 2.2; CPF0201D7K68C1_0201
SJ1: ESP32_C6_LIBRARY_7_JUMPER_SJ
SW2, SW3, SW4: 0; 2025-10-22_07-23-44_LIBRARY_SW_EVP-AKE31A_PAN
TP_BAT_GND: HECTOR_WATCH_1_TPTP20R; HECTOR_WATCH_1_TP20R
TP_ON: HECTOR_WATCH_1_TPTP20R; HECTOR_WATCH_1_TP20R
TP_OP: HECTOR_WATCH_1_TPTP20R; HECTOR_WATCH_1_TP20R
TP_VBAT: HECTOR_WATCH_1_TPTP20R; HECTOR_WATCH_1_TP20R
U3: MAX17048G+T10; ESP32_C6_LIBRARY_SON50P200X200X80-9N

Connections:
3V3: C34.1, IC2.C2 (VDD), Q1.2 (S), R5.2, R7.2, R8.2, R_PWR_EPD.2; also elsewhere on the board
ALERT: U3.5 (!ALERT); also elsewhere on the board
D+: D3.4 (I/O2_2); also elsewhere on the board
D-: D3.6 (I/O1_2); also elsewhere on the board
DN: D3.1 (I/O1_1), J4.A7 (DN1), J4.B7 (DN2)
DP: D3.3 (I/O2_1), J4.A6 (DP1), J4.B6 (DP2)
EPD_3V3: C1-EP-DR.1, EPD_C5.2, J1.15, J1.16, L5.2, Q1.3 (D)
EPD_BUSY: J1.9; also elsewhere on the board
EPD_CS: J1.12; also elsewhere on the board
EPD_DC: J1.11; also elsewhere on the board
EPD_RST: J1.10; also elsewhere on the board
GDR: J1.2, Q3.1 (G), R2_EP_DR.2
GND: C1-EP-DR.2, C27.2, C29.2, C30.2, C31.2, C32.2, C34.2, C42.2, C43.2, D3.2 (GND), D4.1 (K), EPD_C1.1, EPD_C2.1, EPD_C5.1, EPD_C6.1, EPD_C7.1, EPD_C8.1, EPD_C9.1, EPD_C10.1, EPD_C11.1, EPD_C12.1, IC2.B1 (IN/TRIG), IC2.B3 (GND), J1.8, J1.17, J1.MP1, J1.MP2, J4.A1_B12 (GND), J4.A12_B1 (GND), J4.SH1 (SHIELD), J4.SH2 (SHIELD), J4.SH3 (SHIELD), J4.SH4 (SHIELD), R1_USB.2, R2_EP_DR.1, R2_USB.2, R_TYPE_SEL.1, SJ1.1, SW2.1, SW3.1, SW4.1, TP_BAT_GND.TP, U3.1 (CTG), U3.4 (GND), U3.6 (QSTRT), U3.9 (EP); also elsewhere on the board
HAPTIC_EN: IC2.A1 (EN); also elsewhere on the board
MOSI: J1.14; also elsewhere on the board
unnamed: C2-EP-DR.1, D2.1 (K), D4.2 (A)
unnamed: C2-EP-DR.2, D5.2 (A), L5.1, Q3.3 (D)
unnamed: R1_EP_DR.1, R_TYPE_SEL.2, SJ1.2
unnamed: EPD_C1.2, J1.5
unnamed: EPD_C2.2, J1.4
unnamed: EPD_C6.2, J1.18
unnamed: EPD_C7.2, J1.19
unnamed: EPD_C8.2, J1.20
unnamed: C32.1, IC2.A2 (REG)
unnamed: EPD_C10.2, J1.22
unnamed: J4.B5 (CC2), R2_USB.1
unnamed: EPD_C12.2, J1.24
unnamed: J4.A5 (CC1), R1_USB.1
OUT+: IC2.A3 (OUT+), TP_OP.TP
OUT-: IC2.C3 (OUT-), TP_ON.TP
P0.13: C30.1, R5.1, SW4.2; also elsewhere on the board
P0.14: C31.1, R8.1, SW3.2; also elsewhere on the board
P1.01: Q1.1 (G), R_PWR_EPD.1; also elsewhere on the board
P1.02: C29.1, R7.1, SW2.2; also elsewhere on the board
PREVGH: D5.1 (K), EPD_C9.2, J1.21
PREVGL: D2.2 (A), EPD_C11.2, J1.23
RESE: J1.3, Q3.2 (S), R1_EP_DR.2
SCK: J1.13; also elsewhere on the board
SCL: IC2.C1 (SCL), U3.7 (SCL); also elsewhere on the board
SDA: IC2.B2 (SDA), U3.8 (SDA); also elsewhere on the board
VBAT: C27.1, TP_VBAT.TP, U3.2 (CELL), U3.3 (VDD); also elsewhere on the board
VBUS: C42.1, C43.1, D3.5 (VBUS), J4.A4_B9 (VBUS), J4.A9_B4 (VBUS); also elsewhere on the board

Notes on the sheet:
E-Paper Drive Circuit
E-Paper Display Connector
Fuel Gauge
Haptic Driver
Buttons
USB C Connector & ESD Protection

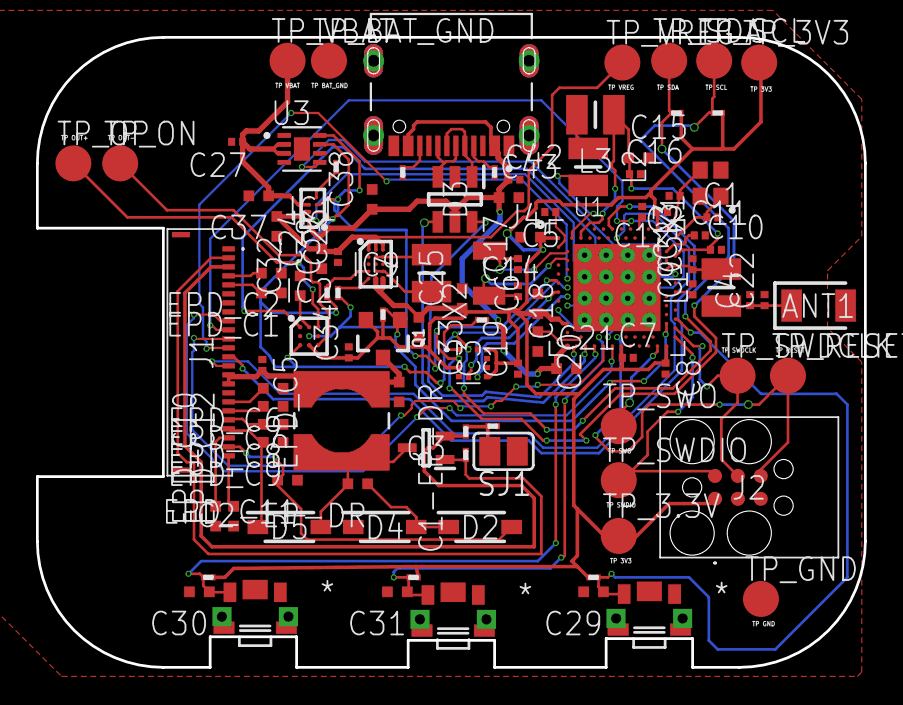
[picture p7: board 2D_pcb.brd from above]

Board: 4 copper layers, 46.0 x 35.0 mm, 105 parts (0 on the bottom side), 70 nets.

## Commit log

2026-04-20 Add files via upload
    last v of schematic and 2d pcb
    [2D_pcb.brd]
2026-04-20 Add files via upload
    added pdf file containing schematic

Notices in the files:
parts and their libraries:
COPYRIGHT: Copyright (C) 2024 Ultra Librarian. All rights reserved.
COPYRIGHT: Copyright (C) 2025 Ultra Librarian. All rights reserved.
